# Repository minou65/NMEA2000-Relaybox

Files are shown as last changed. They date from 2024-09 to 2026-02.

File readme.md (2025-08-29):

# NMEA2000-Relaybox

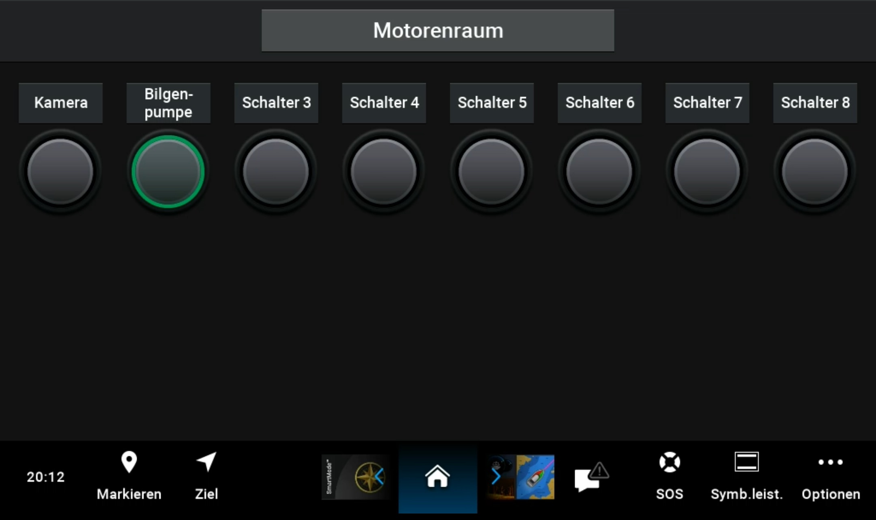
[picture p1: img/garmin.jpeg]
Garmin plotter example


## Overview

The NMEA2000-Relaybox is a flexible and robust device for controlling and monitoring relays over the NMEA2000 network. It is designed for seamless integration with marine electronics, enabling reliable management of electrical components on your vessel.
Relays can also be switched directly from the web interface by clicking the LED button. Additionally, an off-delay (drop-out time) can be configured for each relay, allowing it to automatically switch off after a specified period.

**Key Features:**
- Supports up to 8 relays per device (expandable across multiple devices)
- CAN bus communication via MCP2562
- Web-based configuration interface
- Compatible with plotters supporting PGN 127501 (Binary Switch Bank Status) and PGN 127502 (Switch Bank Control)
- Power supply via NMEA2000 bus

---

## Table of Contents

- [NMEA2000-Relaybox](#nmea2000-relaybox)
  - [Overview](#overview)
  - [Table of Contents](#table-of-contents)
  - [Other NMEA2000 Projects](#other-nmea2000-projects)
  - [Hardware](#hardware)
    - [ESP32\_Relay\_X2 Pinout](#esp32_relay_x2-pinout)
    - [ESP32\_Relay\_X8 Pinout](#esp32_relay_x8-pinout)
  - [Libraries Used](#libraries-used)
  - [Wiring Diagram](#wiring-diagram)
  - [Programming](#programming)
  - [Case and Enclosure](#case-and-enclosure)
  - [Configuration](#configuration)
    - [System Configuration](#system-configuration)
    - [NMEA Configuration](#nmea-configuration)
    - [Relay Configuration](#relay-configuration)
  - [Firmware Update](#firmware-update)
  - [Blink Codes](#blink-codes)
  - [Reset](#reset)
  - [Default Credentials](#default-credentials)
  - [Default IP Address](#default-ip-address)

---

## Other NMEA2000 Projects

In addition to the relay box, the following NMEA2000 projects are also available from the same author:
- [Fluid Level Sensor](https://github.com/minou65/NMEA2000-FluidLevel)
- [DS1820 Temperature Monitor](https://github.com/minou65/NMEA2000-DS1820)
- [BME280 Environmental Sensor](https://github.com/minou65/NMEA2000-BME280)
- [Battery Monitor](https://github.com/minou65/NMEA2000-BatteryMonitor)

---

## Hardware

This project uses either the ESP32_Relay_X2 or ESP32_Relay_X8 board as the base. The MCP2562 chip is connected to the expansion header for CAN bus communication. Power is supplied directly from the NMEA2000 bus. Each relay can switch up to 10A at 30V.

### ESP32_Relay_X2 Pinout
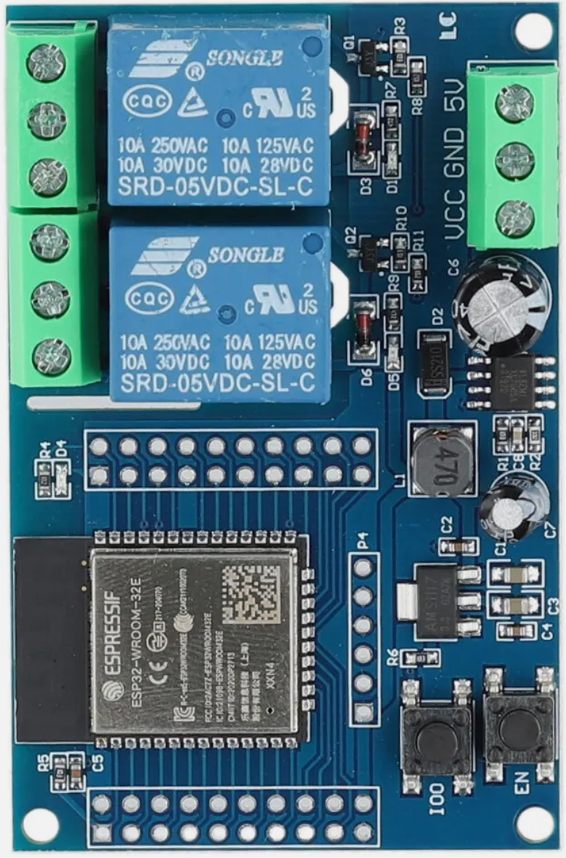
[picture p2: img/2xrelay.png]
ESP32_Relay_X2


| GPIO | Output |
|---|---|
| 16 | Relay 1 |
| 17 | Relay 2 |
| 23 | Internal LED|

### ESP32_Relay_X8 Pinout
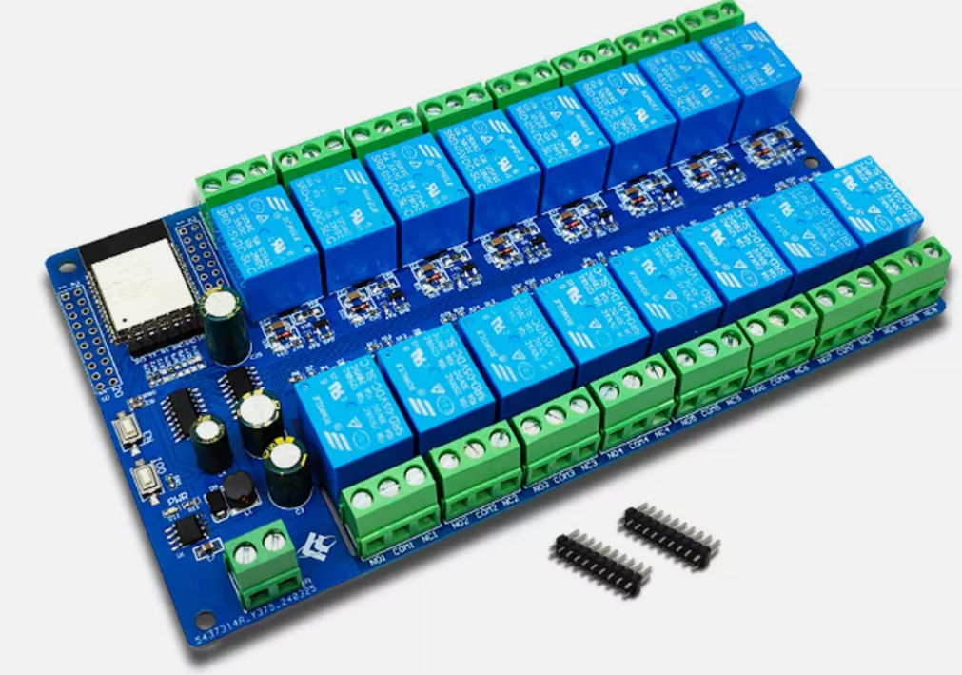
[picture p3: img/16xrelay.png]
ESP32_Relay_X8


| GPIO | Output |
|---|---|
| 32 | Relay 1 |
| 33 | Relay 2 |
| 25 | Relay 3 |
| 26 | Relay 4 |
| 27 | Relay 5 |
| 14 | Relay 6 |
| 12 | Relay 7 |
| 13 | Relay 8 |
| 23 | Internal LED|

---

## Libraries Used

- [NMEA2000](https://github.com/ttlappalainen/NMEA2000)
- [NMEA2000_ESP32](https://github.com/ttlappalainen/NMEA2000_esp32)
- [AsyncTCP (3.2.6)](https://github.com/mathieucarbou/AsyncTCP)
- [ESPAsyncWebServer (3.3.12)](https://github.com/mathieucarbou/ESPAsyncWebServer)
- [WebSerial (2.0.7)](https://github.com/ayushsharma82/WebSerial)
- [IotWebConf](https://github.com/minou65/IotWebConf)
- [IotWebConfAsync (1.0.2)](https://github.com/minou65/IotWebConfAsync)
- [IotWebRoot](https://github.com/minou65/IotWebRoot)

---

## Wiring Diagram

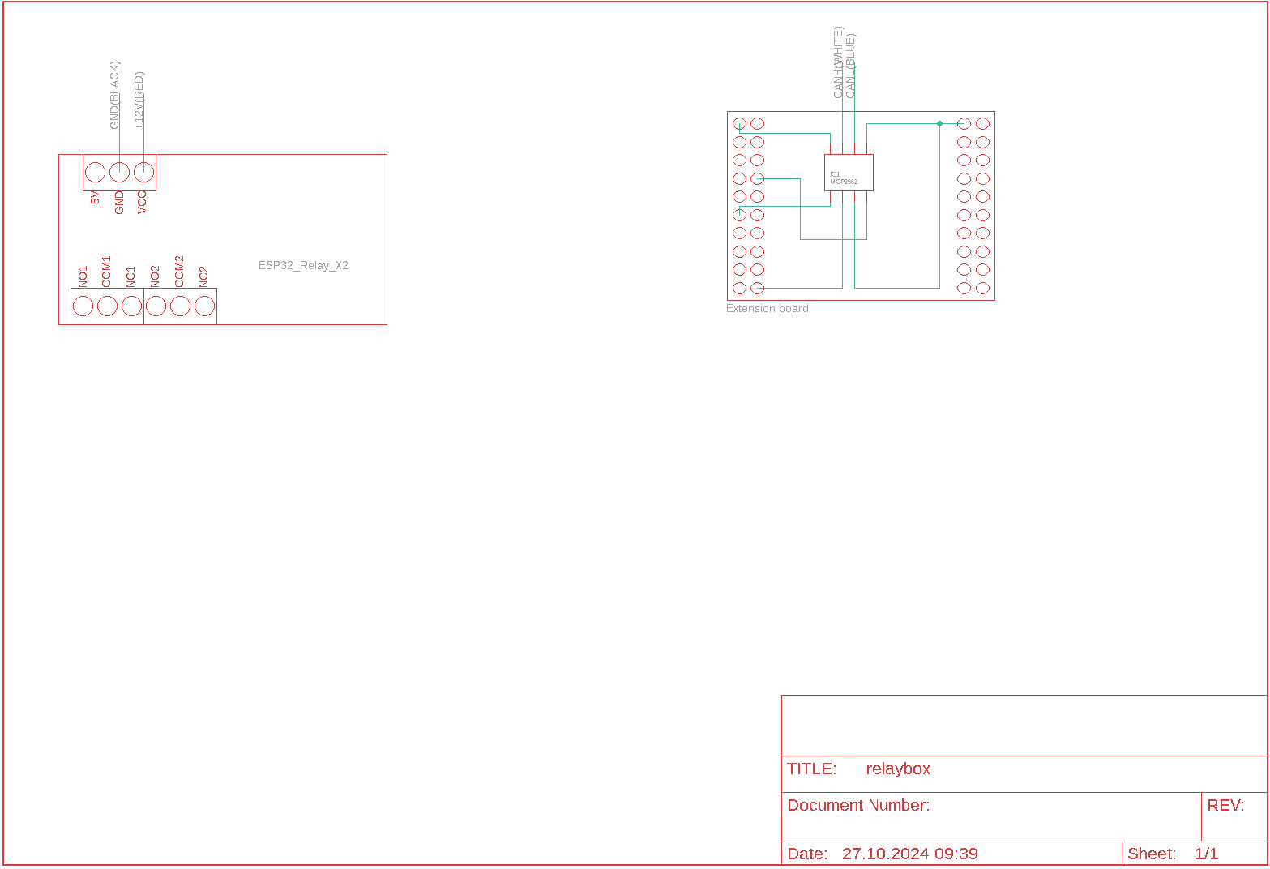
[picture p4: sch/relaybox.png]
Wiring diagram


---

## Programming

To program the ESP32 Relay Box for the first time, you will need a hardware programmer such as the ESP-Prog. The image below shows the pinout of the expansion header.

**Firmware Upload Procedure:**

1. Connect the ESP-Prog (or compatible programmer) to the expansion header as shown in the pinout diagram.
2. To enter programming mode:
  - Press and hold the I00 (GPIO0) button.
  - While holding I00, press the EN (Enable/Reset) button.
  - Release the EN button, then release the I00 button.
  - you will see the following in the Serial output
  ```cpp
  ets Jul 29 2019 12:21:46

rst:0x1 (POWERON_RESET),boot:0x3 (DOWNLOAD_BOOT(UART0/UART1/SDIO_REI_REO_V2))
waiting for download
  ```
3. Start the firmware upload from your development environment (e.g., Arduino IDE, PlatformIO).
4. Once the upload is complete, press the EN button again to restart the device.

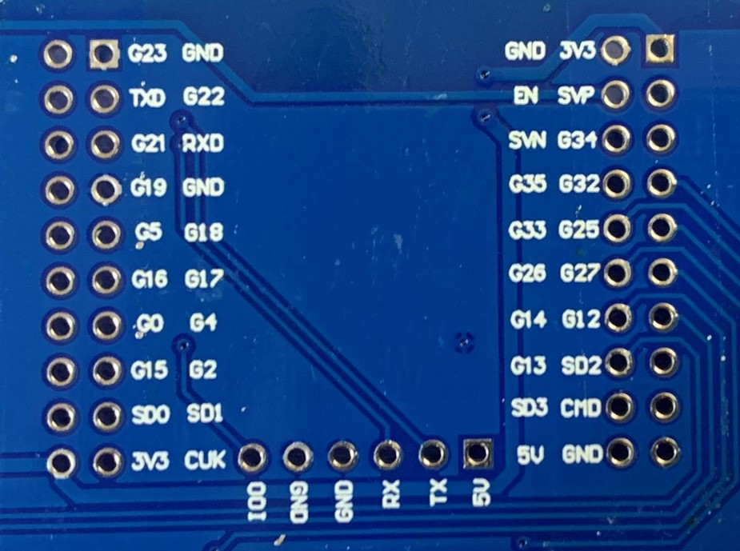
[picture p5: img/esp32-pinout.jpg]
ESP32 expansion header pinout


---

## Case and Enclosure

STL files for 3D printing the case and lid are available in the `stl` folder.

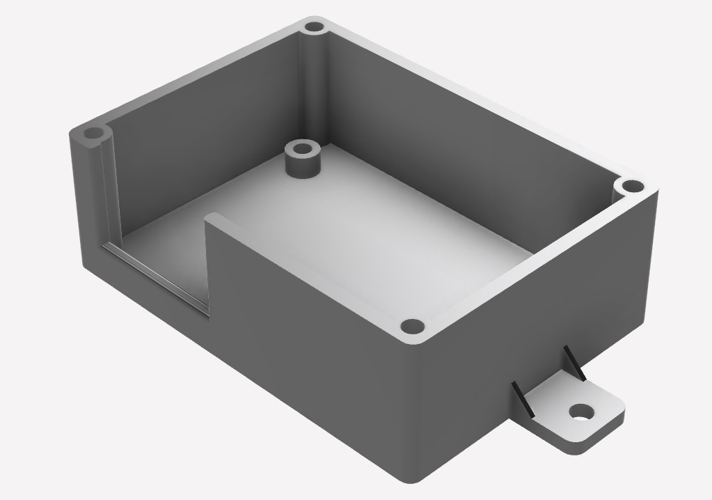
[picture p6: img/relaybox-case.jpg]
Case
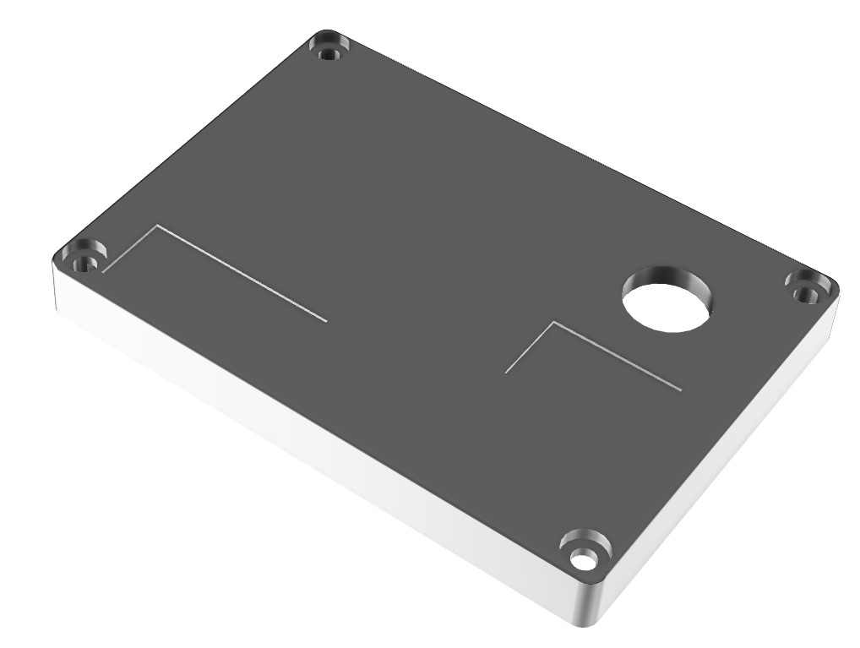
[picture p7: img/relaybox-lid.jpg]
Lid
 
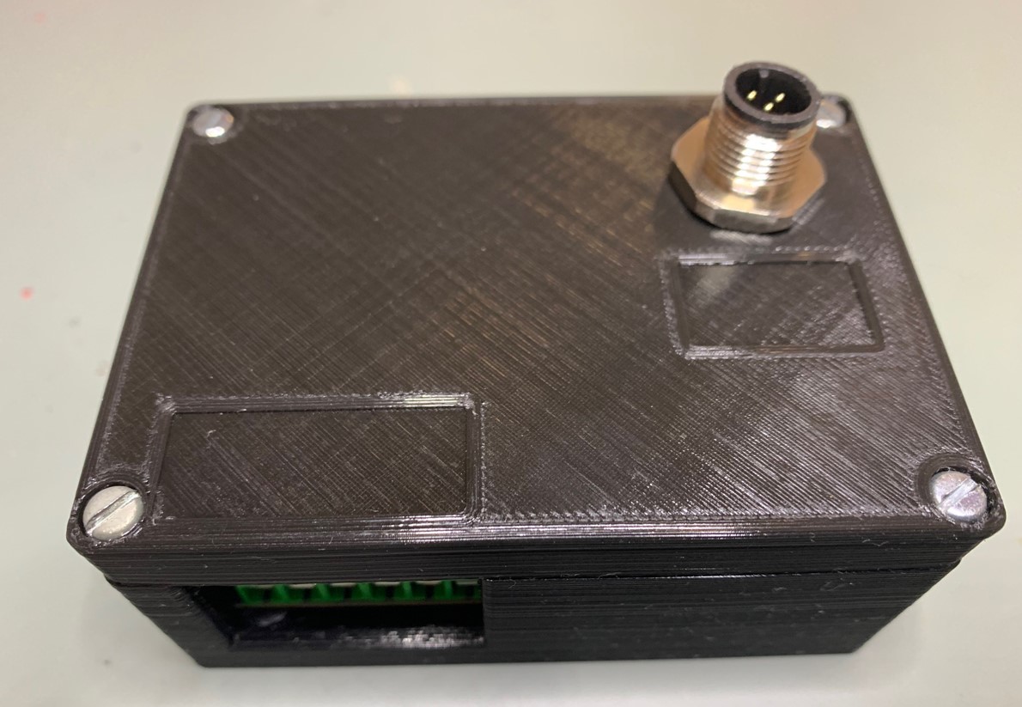
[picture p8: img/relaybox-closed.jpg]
Closed
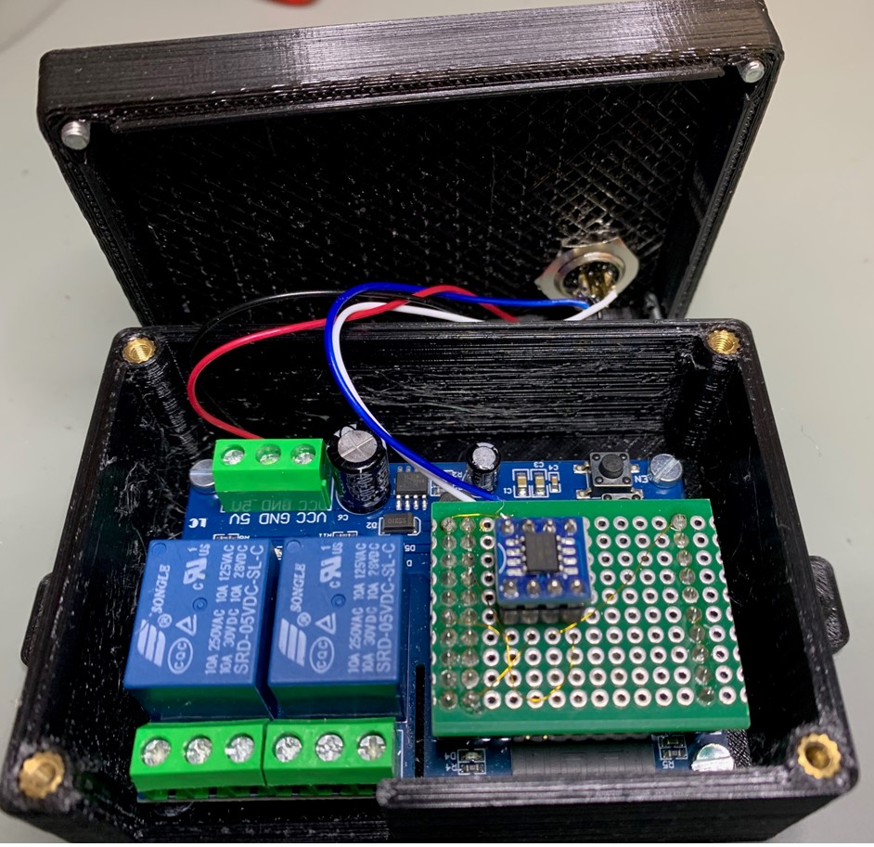
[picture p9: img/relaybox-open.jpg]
Open
 

---

## Configuration

After the first boot, some values must be configured. Items marked with * are mandatory.

### System Configuration

- **Thing Name**: Assign a unique, descriptive name to the device (e.g., `relays_engine_room`). Use only English letters and underscores.
- **AP Password**: Set a secure password (8–32 characters, at least 12 recommended, with 3 character classes).*
- **WiFi SSID**: Name of the WiFi network to connect to.*
- **WiFi Password**: Password for the WiFi network above.*
- **AP Offline Mode (minutes)**: Set how long the AP should remain enabled after startup (0 = always enabled, up to 30 minutes).

### NMEA Configuration

- **Instance**: Should be unique for each device sending this PGN.*
- **SID**: Sequence identifier (usually 255).
- **Switch Bank Address**: Unique identifier for each device on the NMEA2000 network (up to 254 devices).

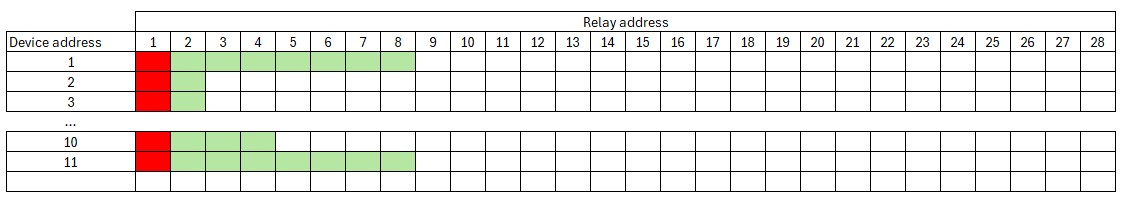
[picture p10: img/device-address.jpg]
Device address


- **Relay Address**: Identifies which relay is controlled. Each switch bank can control up to 28 relays. Normally, the relay address is 1. If you use multiple relay boxes in one switch bank, set the correct relay address accordingly.

Relay address

### Relay Configuration

- **GPIO**: The GPIO pin used for the relay.
- **Off Time (s)**: Time in seconds before the relay switches off automatically. If set to 0 (default), the relay remains on indefinitely.

---

## Firmware Update

To update the firmware, open the Configuration page in the web interface and click on the Firmware Update link. Follow the on-screen instructions.

---

## Blink Codes

| Blinking Pattern | Meaning |
|---|---|
| Rapid blinking (mostly on, short off) | Access Point mode: device creates its own WiFi network. |
| Alternating on/off blinking | Connecting to configured WiFi network. |
| Mostly off, short flash | Device is online. |
| Mostly off, long flash | Device is in offline mode. |

---

## Reset

To reset the device, pull the CONFIG_PIN (GPIO 13) to ground during startup. The device will use the initial password to build an AP (useful if the password is lost).

---

## Default Credentials

- **Username:** admin
- **Default password (when not connected to an AP):** 123456789

## Default IP Address

When in AP mode, the default IP address is `192.168.4.1`.

---

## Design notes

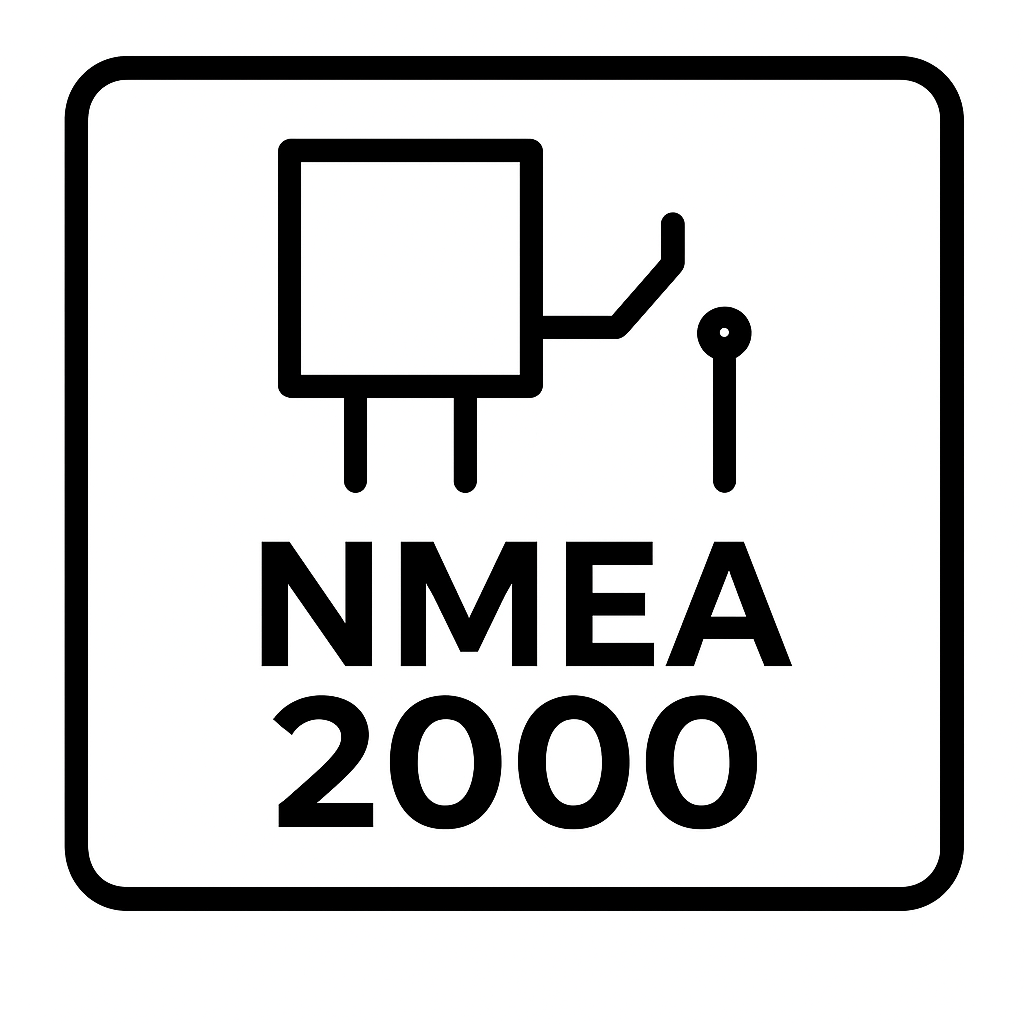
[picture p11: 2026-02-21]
img/nmea2000-relay.png

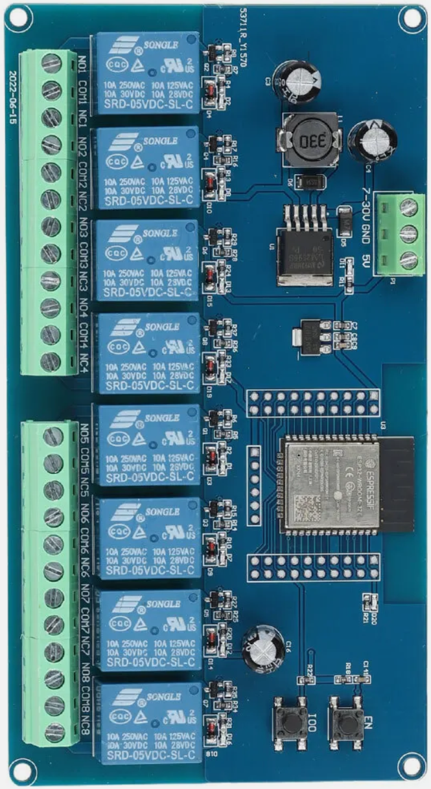
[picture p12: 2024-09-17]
img/8xrelay.png

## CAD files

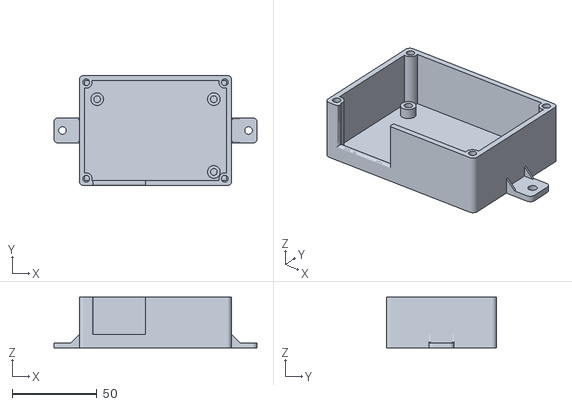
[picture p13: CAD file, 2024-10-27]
stl/NMEA2000-Relaybox-case.stl
120.0 x 65.0 x 30.0

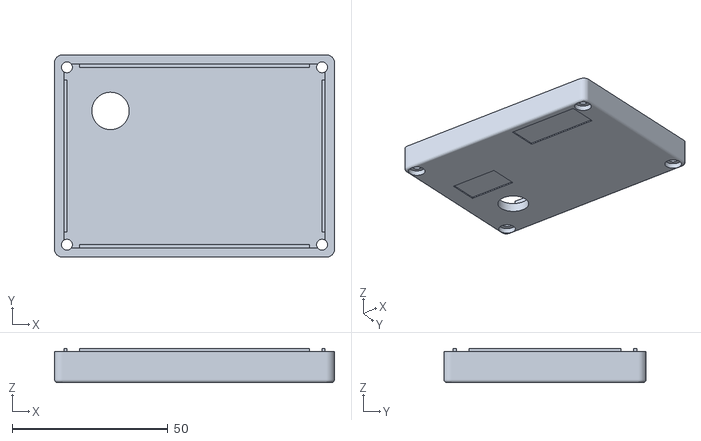
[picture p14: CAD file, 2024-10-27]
stl/NMEA2000-Relaybox-lid.stl
90.0 x 65.0 x 11.0

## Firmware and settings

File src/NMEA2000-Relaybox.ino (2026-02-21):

/*
Name: NMEA2000-Relaybox

Description: 
NMEA2000 Relaybox firmware for ESP32/ESP8266. Provides web interface for configuration 
and control of relays, and handles NMEA2000 communication.

Author: andy

WEMOS D1 MINI ESP32
*/
#define TESTMODE 0 // Enable test mode for relays (only first run, then normal operation). Set to 0 to disable test mode.

#include <Arduino.h>

#include "common.h"
#include "webhandling.h"
#include "version.h"
#include <NMEA2000_esp32.h>
#include "NMEAHandling.h"

#include "neotimer.h"


#if TESTMODE == 1

// Test mode variables
bool relayTestActive = true;
uint8_t relayTestIndex = 0;
bool relayTestTurnOff = false;
Neotimer relayTestTimer = Neotimer(1000); // 1 second timer

#endif // TESTMODE == 1



bool SaveConfiguration = false;
bool ChangedConfiguration = false;

char Version[] = VERSION_STR; // Manufacturer's Software version code

void setup() {

    Serial.begin(115200);
    while (!Serial) {
        delay(1);
    }

    Serial.printf("Firmware version:%s\n", Version);

    webinit();
	N2kBegin();

    Serial.println("device initilized");

#if TESTMODE == 1
    relayTestTimer.start();
#endif // TESTMODE == 1

}

void loop() {
  
    webLoop();
    N2kLoop();
    ChangedConfiguration = false;

#if TESTMODE == 1
    // Relay test loop
    if (relayTestActive) {
        if (!relayTestTurnOff) {
            if (relayTestTimer.done()) {
                // Turn on next relay
                SetSwitchStatus(relayTestIndex, true);
                relayTestIndex++;
                relayTestTimer.start();

                // Count active relays
                uint8_t activeCount = 0;
                Relay* relay_ = &Relay1;
                while (relay_ != nullptr) {
                    if (relay_->isActive()) activeCount++;
                    relay_ = (Relay*)relay_->getNext();
                }

                // If all relays have been turned on, prepare to turn all off
                if (relayTestIndex >= activeCount) {
                    relayTestTurnOff = true;
                    relayTestTimer.start();
                }
            }
        }
        else {
            if (relayTestTimer.done()) {
                // Turn all relays off
                uint8_t idx = 0;
                Relay* relay_ = &Relay1;
                while (relay_ != nullptr) {
                    if (relay_->isActive()) {
                        SetSwitchStatus(idx, false);
                    }
                    relay_ = (Relay*)relay_->getNext();
                    idx++;
                }
                relayTestActive = false; // Stop test mode after one run
            }
        }
        return; // Skip normal relay processing during test
    }
#endif // TESTMODE == 1

    uint8_t output_ = 0;
    Relay* relay_ = &Relay1;
    while (relay_ != nullptr) {
        if (relay_->isActive()) {
            if (relay_->isTimerDone()) {
                SendSwitchStatus(output_, false);
            }
            relay_->process();
        }
        relay_ = (Relay*)relay_->getNext();
        output_++;
    }
}

void SetSwitchStatus(uint8_t output, bool ItemStatus) {
    Relay* relay_ = &Relay1;
    uint8_t relayIndex_ = 0;
    while (relay_ != nullptr) {
        if (relay_->isActive()) {
            if (relayIndex_ == output) {
                if (relay_->Status() != (ItemStatus ? N2kOnOff_On : N2kOnOff_Off)) {
                    if (ItemStatus) {
                        relay_->On();
                    }
                    else {
                        relay_->Off();
                    }
                    SendSwitchStatus(output, ItemStatus);
                }
            }
        }
        relay_ = (Relay*)relay_->getNext();
        relayIndex_++;
    }
}

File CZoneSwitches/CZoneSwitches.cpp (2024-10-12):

// 
// 
// 

#include "CZoneSwitches.h"
#include "common.h"
#include <NMEA2000_CAN.h>

#define CzSwitchBank1SerialNum  0x1d // Serial Number switches 1-4 (00260128)
#define CzSwitchBank2SerialNum  0x1b // Serial Number switches 5-8  (00260126)

tN2kSyncScheduler CzUpdatePeriod65284(false, 2000, 500);
tN2kSyncScheduler CzUpdatePeriod65283(false, 500, 100);
tN2kSyncScheduler CzUpdatePeriod127501(false, 10000, 1000);

uint8_t CzRelayPinMap[] = { 13,14,15,16,17,18,19,20 }; // arduino pins driving relays i.e CzRelayPinMap[0] returns the pin number of Relay 1
tN2kBinaryStatus CzBankStatus;
uint8_t CzSwitchState1 = 0;
uint8_t CzSwitchState2 = 0;
uint8_t CzMfdDisplaySyncState1 = 0;
uint8_t CzMfdDisplaySyncState2 = 0;
bool    CzConfigAuthenticated = false;

typedef struct {
    unsigned long PGN;
    void (*Handler)(const tN2kMsg& N2kMsg);
} tNMEA2000Handler;

tNMEA2000Handler NMEA2000Handlers[] = {
    {65280L,ParseCZoneMFDSwitchChangeRequest65280},
    {65290L,ParseCZoneConfigRequest65290},
    {65284L,ParseMDF65284},
    {65288L,ParseMDF65288},
    {127502L,ParseN2kPGN127502},
    {0,0}
};

// List here messages your device will transmit.
const unsigned long TransmitMessages[] PROGMEM = {
    65284L,
    65283L,
    65290L,
    127501L,
    127502L,
    0
};

const unsigned long ReciveMessages[] PROGMEM = {
    65284L,
    65283L,
    65290L,
    127501L,
    127502L,
    0
};

void CZoneSetup() {
    uint8_t _chipid[6];
    uint32_t _id = 0;

    // Generate unique number from chip id
    esp_efuse_mac_get_default(_chipid);
    for (int _i = 0; _i < 6; _i++) _id += (_chipid[_i] << (7 * _i));

    for (uint8_t i = 0; i < NumberOfSwitches; i++)
        pinMode(CzRelayPinMap[i], OUTPUT);

    N2kResetBinaryStatus(CzBankStatus);

    // Reserve enough buffer for sending all messages. This does not work on small memory devices like Uno or Mega
    NMEA2000.SetN2kCANMsgBufSize(8);
    NMEA2000.SetN2kCANReceiveFrameBufSize(150);
    NMEA2000.SetN2kCANSendFrameBufSize(150);

    // Set Product information
    NMEA2000.SetProductInformation(
        "1", // Manufacturer's Model serial code
        100, // Manufacturer's product code
        "Relaybox",  // Manufacturer's Model ID
        Version,  // Manufacturer's Software version code
        Version // Manufacturer's Model version
    );

    NMEA2000.SetDeviceInformation(
        _id, // Unique number. Use e.g. Serial number.
        135, // Device function=Switch Interface. See DEVICE_FUNCTION (0 - 255) https://canboat.github.io/canboat/canboat.html#main
        110, // Device class=Switch Interface. DEVICE_CLASS (0 - 127) https://canboat.github.io/canboat/canboat.html#main
        2040 // Just choosen free from code list on MANUFACTURER_CODE (0 - 2047) https://canboat.github.io/canboat/canboat.html#main
    );

    NMEA2000.SetMode(tNMEA2000::N2km_ListenAndNode);
    NMEA2000.SetN2kSource(N2KSource);
    NMEA2000.EnableForward(false);

    // Here we tell library, which PGNs we transmit and recive
    NMEA2000.ExtendTransmitMessages(TransmitMessages);
    NMEA2000.ExtendReceiveMessages(ReciveMessages);

    NMEA2000.SetOnOpen(CZoneOpen);

    NMEA2000.SetMsgHandler(CZoneHandleMessage);

    NMEA2000.Open();
}

void CZoneOpen() {
	CzUpdatePeriod65284.UpdateNextTime();
	CzUpdatePeriod65283.UpdateNextTime();
	CzUpdatePeriod127501.UpdateNextTime();
}

void CZoneLoop() {
    NMEA2000.ParseMessages();

	if (CzUpdatePeriod65284.IsTime()) {
		CzUpdatePeriod65284.UpdateNextTime();
		SendCZoneSwitchHeartbeat65284(CzSwitchBank1SerialNum);
		SendCZoneSwitchHeartbeat65284(CzSwitchBank2SerialNum);
	}

	if (CzUpdatePeriod65283.IsTime()) {
		CzUpdatePeriod65283.UpdateNextTime();
		SendCZoneSwitchChangeAck65283(CzSwitchBank1SerialNum);
		SendCZoneSwitchChangeAck65283(CzSwitchBank2SerialNum);
	}

	if (CzUpdatePeriod127501.IsTime()) {
		CzUpdatePeriod127501.UpdateNextTime();
		SendCZoneSwitchState127501(BinaryDeviceInstance);
	}

    if (NMEA2000.GetN2kSource() != N2KSource) {
        N2KSource = NMEA2000.GetN2kSource();
        SaveConfiguration = true;
    }
}

void CZoneHandleMessage(const tN2kMsg& N2kMsg) {
    int iHandler;
    for (iHandler = 0; NMEA2000Handlers[iHandler].PGN != 0 && !(N2kMsg.PGN == NMEA2000Handlers[iHandler].PGN); iHandler++);
    if (NMEA2000Handlers[iHandler].PGN != 0) {
        NMEA2000Handlers[iHandler].Handler(N2kMsg);
    }
}

void SetChangeSwitchState(uint8_t SwitchIndex, bool ItemStatus) {
    // Set or reset the relay
    if (ItemStatus)
        digitalWrite(CzRelayPinMap[SwitchIndex - 1], HIGH); // adjust SwitchIndex to CzRelayPinMap value and set or reset
    else
        digitalWrite(CzRelayPinMap[SwitchIndex - 1], LOW);
    //send out change and status to other N2k devices on network
    SendCZoneSwitchState127501(DeviceInstance);
    SendCZoneSwitchChangeRequest127502(DeviceInstance, SwitchIndex, ItemStatus);
}

void SetN2kSwitchBankCommand(tN2kMsg& N2kMsg, unsigned char DeviceBankInstance, tN2kBinaryStatus BankStatus){
    SetN2kPGN127502(N2kMsg, DeviceBankInstance, BankStatus);
}


// ********************************************************************************************
//      PGN65280 sent from controlling MFD to request a change of state of a single switch
//      The command Byte 2 = Bit to change 0x05 = Sw 1, 0x06 = Sw 2, 0x07 = Sw 3, 0x08 = Sw4
//      byte6 == 0xF1 set switch on, or 0xF2 reset the switch off and initiates the sending of the following:
//      PGN12501, PGN12502 for compatability With NMEA2000 switching from the switching device.
//      After the response has been sent, the MFD sends a PNG65280 with Byte 6 equal 0x40 to indicate success 
//      PGN65283 is then sent from the switching device.
//
// ********************************************************************************************
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

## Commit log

2024-09-17 error message extended with allowed pins
    [webhandling.cpp]
2024-09-18 Device and relay default addresses and handling changed
2024-10-23 Add ESP32DA binary file to source directory
2024-10-23 added different configuration for ARDUINO_ESP_DEV and ARDUINO_ESP32_WROOM_DA
2024-10-23 fixed bug in SetCZRelayOutput function
    [NMEA2000-Relaybox.ino]
2024-10-23 Refactor relay off-time handling
2024-10-26 Refactor pin configuration for ESP32 in webhandling.cpp
2024-10-26 Remove unused SwitchBankStatusScheduler
2024-10-26 Refactor relay control logic
2024-10-26 Refactor relay control logic and update switch bank command handling
2024-10-27 set correct output pins after config is saved
    [webhandling.cpp]
2024-10-27 initial version
    [NMEA2000-Relaybox-case.stl, NMEA2000-Relaybox-lid.stl]
2024-10-27 Update switch bank address parameter name
2024-10-28 fixed relay offset
2024-10-28 Refactor relay index variable
2024-10-28 Refactor relay initialization and configuration
2024-11-07 corrected spelling of "Relais" to "Relay"
2025-04-14 Refactor Watchdog Timer configuration for clarity and initialization
2025-05-30 Set ArduinoOTA hostname to the Thing's name
2025-08-29 Refactor switch handling and logging in web handling module
2025-08-29 Add relay control endpoint and update web interface for relay toggling
2025-08-29 Refactor test mode implementation and remove watchdog timer configuration
2026-01-11 Refactor: reverted includes from header file
    [webhandling.h]
